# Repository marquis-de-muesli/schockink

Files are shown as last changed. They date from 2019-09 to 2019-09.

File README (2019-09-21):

NOTE: Schematics+Board are still IN-PROGRESS, i will announce once i am confident enough in them to put them into production myself.

How small can you go while keeping the full power and same (+more) features of a mk-312 box? :)
The answer is about 90x70x35mm, or about 1/8th of the original box.

Much thanks goes to metafetish and the buttshock project where i got started with the schematics.

To save cost and space, the entire control panel with LCD and mechanical buttons had to go.
The idea is to make a bluetooth app to take control instead.

Another major difference is that instead of a simple bluetooth bridge (HC05) i plopped in a whole new powerfull MCU (ESP32) on top of the original hardware.
The reason is twofold.
- The one thing we cant really replace with the ErosLink Protocol is the MA Knob, which is now replaced by a DigPot controlled by our new MCU.
- Eventually the idea is to tinker around with a new firmware from scratch, not just reuse the ET312 one.
  This Design allows to take full control of the Output Stage in the future.

Power will be supplied by 3x 18650 Lithium Cells. 
As of right now i haven't been able to cram in a charging circuit. So for now they are removable and charged in a tabletop charger.
The unintended side effect is that you could keep a spare set of batteries charged.

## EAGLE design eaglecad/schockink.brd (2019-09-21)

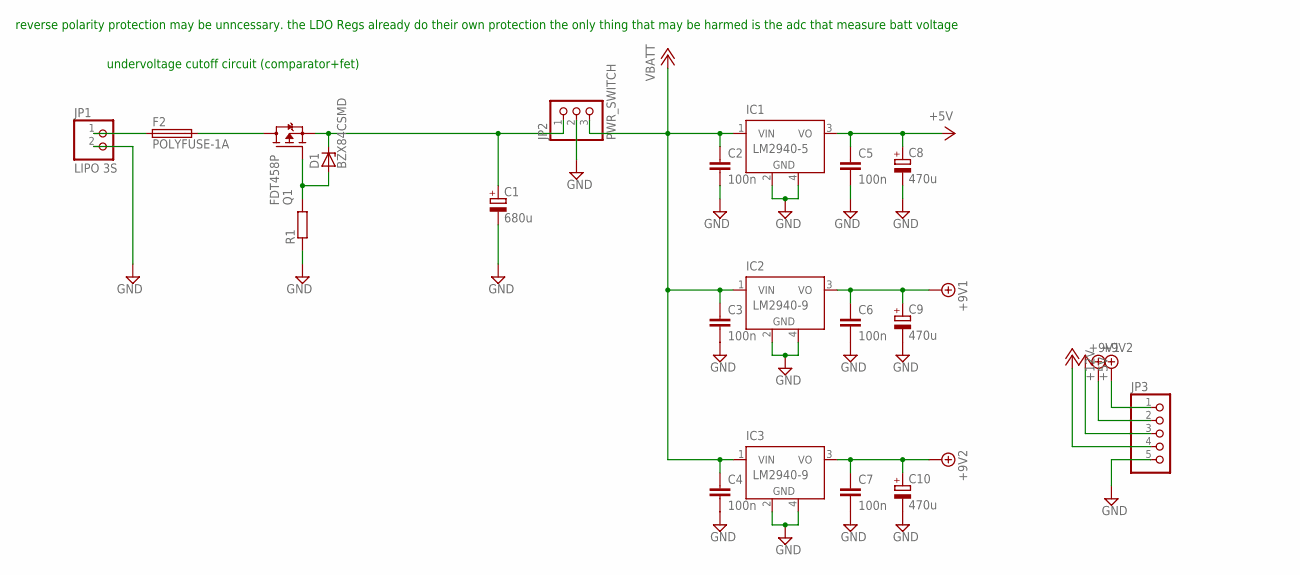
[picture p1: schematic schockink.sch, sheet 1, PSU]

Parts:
C1: 680u; UD-8X10_NICHICON
C2, C3, C4, C5, C6, C7: 100n; C2012
C8, C9, C10: 470u; UD-6,3X7,7_NICHICON
D1: BZX84CSMD; TO236
F2: POLYFUSE-1A; R1210
IC1: LM2940-5; SOT223
IC2, IC3: LM2940-9; SOT223
JP1: LIPO 3S; 1X02
JP2: PWR_SWITCH; 1X03
JP3: PINHD-1X5; 1X05
Q1: FDT458P; SOT223; MOUSER# 512-FDT458P
R1: R-EU_M2012; M2012

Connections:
+5V: C5.1, C8.+, IC1.3 (VO), JP3.3; also elsewhere on the board
+9V1: C6.1, C9.+, IC2.3 (VO), JP3.2; also elsewhere on the board
+9V2: C7.1, C10.+, IC3.3 (VO), JP3.1; also elsewhere on the board
+VBATT: C2.1, C3.1, C4.1, IC1.1 (VIN), IC2.1 (VIN), IC3.1 (VIN), JP2.3, JP3.4; also elsewhere on the board
GND: C1.-, C2.2, C3.2, C4.2, C5.2, C6.2, C7.2, C8.-, C9.-, C10.-, IC1.2 (GND), IC1.4 (GND), IC2.2 (GND), IC2.4 (GND), IC3.2 (GND), IC3.4 (GND), JP1.2, JP2.2, JP3.5, R1.1; also elsewhere on the board
unnamed: F2.1, JP1.1
unnamed: F2.2, Q1.2 (D), Q1.4 (D)
unnamed: D1.A, Q1.1 (G), R1.2
unnamed: C1.+, D1.C, JP2.1, Q1.3 (S)

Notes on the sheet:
reverse polarity protection may be unncessary. the LDO Regs already do their own protection the only thing that may be harmed is the adc that measure batt voltage
undervoltage cutoff circuit (comparator+fet)

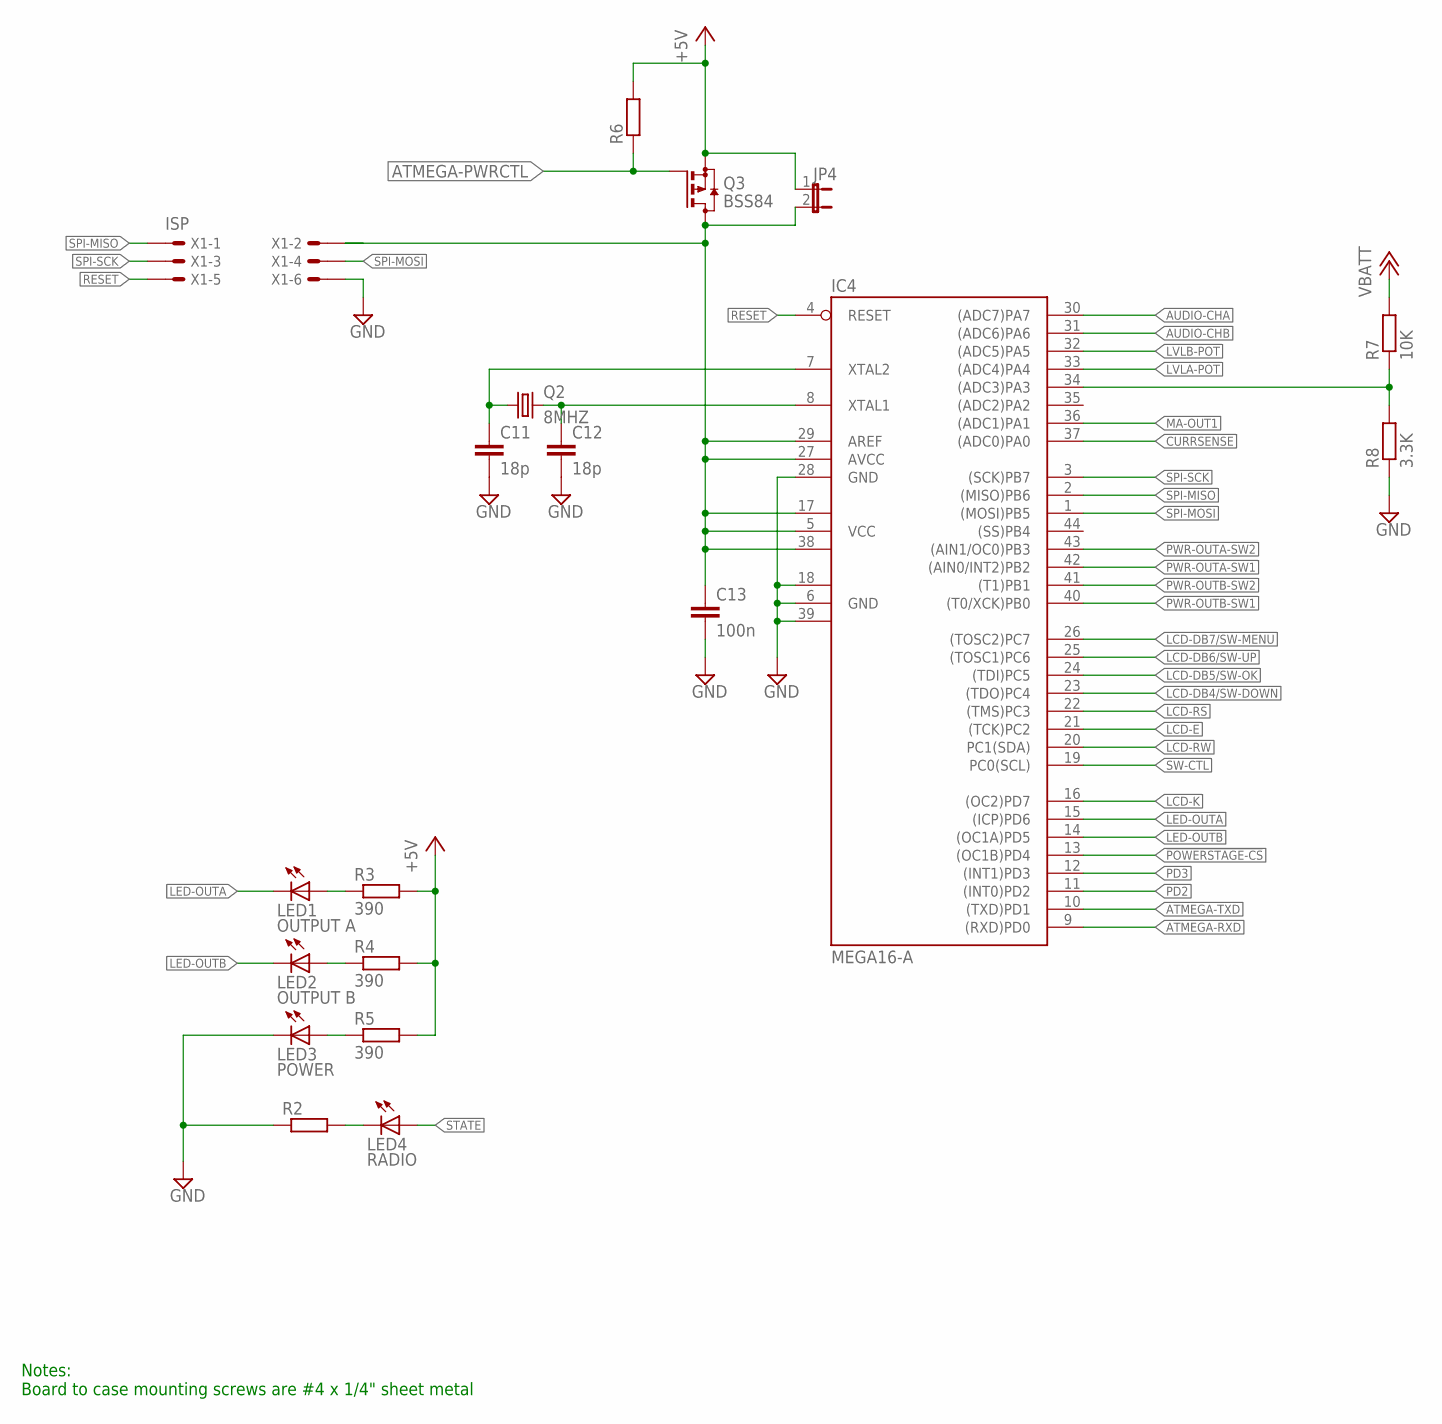
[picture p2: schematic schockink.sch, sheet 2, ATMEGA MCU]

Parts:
C11, C12: 18p; C2012
C13: 100n; C2012
IC4: MEGA16-A; TQFP44
JP4: JP1E; JP1
LED1: OUTPUT A; CHIPLED_0805
LED2: OUTPUT B; CHIPLED_0805
LED3: POWER; CHIPLED_0805
LED4: RADIO; CHIPLED_0805
Q2: 8MHZ; CTS406
Q3: BSS84; SOT23
R2, R6: R-EU_M2012; M2012
R3, R4, R5: 390; M2012
R7: 10K; M2012
R8: 3.3K; M2012
X1: ISP; 057-006-1

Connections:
!POWERSTAGE-CS: IC4.13 ((OC1B)PD4); also elsewhere on the board
+5V: JP4.1, Q3.2 (S), R3.2, R4.2, R5.2, R6.2; also elsewhere on the board
+VBATT: R7.2; also elsewhere on the board
ATMEGA-PWRCTL: Q3.1 (G), R6.1; also elsewhere on the board
ATMEGA-RXD: IC4.9 ((RXD)PD0); also elsewhere on the board
ATMEGA-TXD: IC4.10 ((TXD)PD1); also elsewhere on the board
AUDIO-CHA: IC4.30 ((ADC7)PA7); also elsewhere on the board
AUDIO-CHB: IC4.31 ((ADC6)PA6); also elsewhere on the board
CURRSENSE: IC4.37 ((ADC0)PA0); also elsewhere on the board
GND: C11.2, C12.2, C13.2, IC4.6 (GND), IC4.18 (GND1), IC4.28 (GND), IC4.39 (GND2), LED3.C, R2.1, R8.1, X1.6; also elsewhere on the board
LCD-DB4/SW-DOWN: IC4.23 ((TDO)PC4); also elsewhere on the board
LCD-DB5/SW-OK: IC4.24 ((TDI)PC5); also elsewhere on the board
LCD-DB6/SW-UP: IC4.25 ((TOSC1)PC6); also elsewhere on the board
LCD-DB7/SW-MENU: IC4.26 ((TOSC2)PC7); also elsewhere on the board
LCD-E: IC4.21 ((TCK)PC2); also elsewhere on the board
LCD-K: IC4.16 ((OC2)PD7)
LCD-RS: IC4.22 ((TMS)PC3); also elsewhere on the board
LCD-RW: IC4.20 (PC1(SDA))
LED-OUTA: IC4.15 ((ICP)PD6), LED1.C
LED-OUTB: IC4.14 ((OC1A)PD5), LED2.C
LVLA-POT: IC4.33 ((ADC4)PA4)
LVLB-POT: IC4.32 ((ADC5)PA5)
MA-OUT1: IC4.36 ((ADC1)PA1); also elsewhere on the board
unnamed: IC4.34 ((ADC3)PA3), R7.1, R8.2
unnamed: C13.1, IC4.5 (VCC), IC4.17 (VCC1), IC4.27 (AVCC), IC4.29 (AREF), IC4.38 (VCC2), JP4.2, Q3.3 (D), X1.2
unnamed: LED4.C, R2.2
unnamed: C12.1, IC4.8 (XTAL1), Q2.3 (2)
unnamed: LED2.A, R4.1
unnamed: LED1.A, R3.1
unnamed: C11.1, IC4.7 (XTAL2), Q2.1
unnamed: LED3.A, R5.1
PD2: IC4.11 ((INT0)PD2); also elsewhere on the board
PD3: IC4.12 ((INT1)PD3); also elsewhere on the board
PWR-OUTA-SW1: IC4.42 ((AIN0/INT2)PB2); also elsewhere on the board
PWR-OUTA-SW2: IC4.43 ((AIN1/OC0)PB3); also elsewhere on the board
PWR-OUTB-SW1: IC4.40 ((T0/XCK)PB0); also elsewhere on the board
PWR-OUTB-SW2: IC4.41 ((T1)PB1); also elsewhere on the board
RESET: IC4.4 (RESET), X1.5
SPI-MISO: IC4.2 ((MISO)PB6), X1.1
SPI-MOSI: IC4.1 ((MOSI)PB5), X1.4; also elsewhere on the board
SPI-SCK: IC4.3 ((SCK)PB7), X1.3; also elsewhere on the board
STATE: LED4.A; also elsewhere on the board
SW-CTL: IC4.19 (PC0(SCL)); also elsewhere on the board

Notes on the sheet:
Notes: Board to case mounting screws are #4 x 1/4" sheet metal

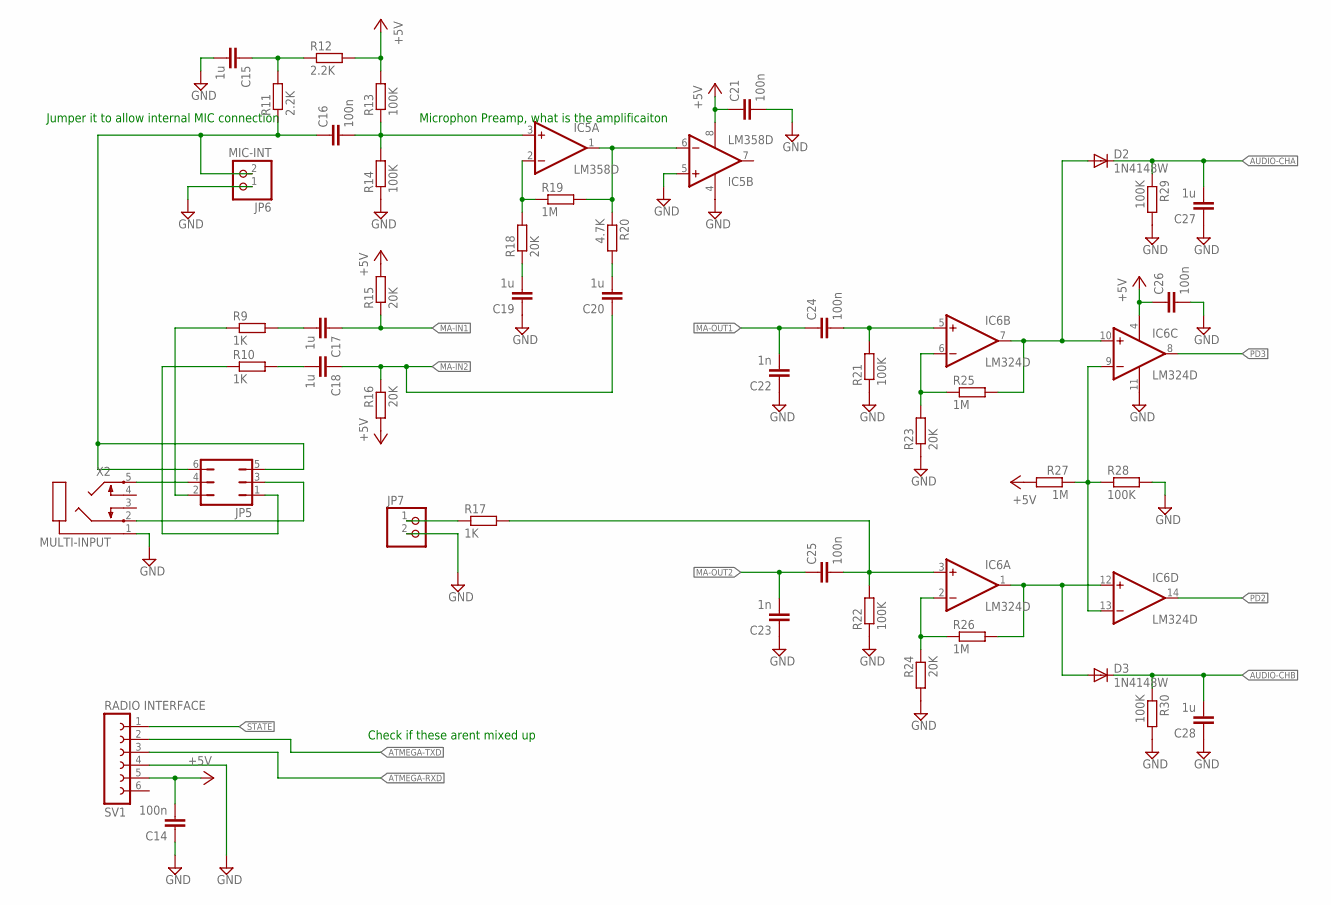
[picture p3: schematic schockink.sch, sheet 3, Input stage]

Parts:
C14, C16, C21, C24, C25, C26: 100n; C2012
C15, C17, C18, C19, C20, C27, C28: 1u; C2012
C22, C23: 1n; C2012
D2, D3: 1N4148W; SOD-123_MINI-SMA
IC5: LM358D; SO08
IC6: LM324D; SO14
JP5: JP3Q
JP6: MIC-INT; 1X02
JP7: PINHD-1X2; 1X02
R9, R10, R17: 1K; M2012
R11, R12: 2.2K; M2012
R13, R14, R21, R22, R28, R29, R30: 100K; M2012
R15, R16, R18, R23, R24: 20K; M2012
R19, R25, R26, R27: 1M; M2012
R20: 4.7K; M2012
SV1: RADIO INTERFACE; FE06
X2: MULTI-INPUT; STX3100

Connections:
+5V: C14.2, C21.1, C26.1, IC5.8 (V+), IC6.4 (V+), R12.2, R13.2, R15.2, R16.2, R27.2, SV1.5; also elsewhere on the board
ATMEGA-RXD: SV1.3; also elsewhere on the board
ATMEGA-TXD: SV1.2; also elsewhere on the board
AUDIO-CHA: C27.2, D2.C, R29.1; also elsewhere on the board
AUDIO-CHB: C28.2, D3.C, R30.1; also elsewhere on the board
GND: C14.1, C15.2, C19.1, C21.2, C22.1, C23.1, C26.2, C27.1, C28.1, IC5.4 (V-), IC5.5 (+IN), IC6.11 (V-), JP6.1, JP7.2, R14.1, R21.1, R22.1, R23.1, R24.2, R28.2, R29.2, R30.2, SV1.4, X2.1; also elsewhere on the board
MA-IN1: C17.1, R15.1; also elsewhere on the board
MA-IN2: C18.1, C20.1, R16.1; also elsewhere on the board
MA-OUT1: C22.2, C24.1; also elsewhere on the board
MA-OUT2: C23.2, C25.1; also elsewhere on the board
unnamed: JP7.1, R17.1
unnamed: JP5.4, X2.5
unnamed: JP5.3, X2.2
unnamed: C25.2, IC6.3 (+IN), R17.2, R22.2
unnamed: JP5.2, R9.1
unnamed: JP5.1, R10.1
unnamed: C19.2, R18.1
unnamed: IC6.2 (-IN), R24.1, R26.1
unnamed: D3.A, IC6.1 (OUT), IC6.12 (+IN), R26.2
unnamed: C17.2, R9.2
unnamed: IC6.6 (-IN), R23.2, R25.1
unnamed: IC6.9 (-IN), IC6.13 (-IN), R27.1, R28.1
unnamed: C24.2, IC6.5 (+IN), R21.2
unnamed: C18.2, R10.2
unnamed: D2.A, IC6.7 (OUT), IC6.10 (+IN), R25.2
unnamed: C16.1, JP5.5, JP5.6, JP6.2, R11.1
unnamed: C15.1, R11.2, R12.1
unnamed: C16.2, IC5.3 (+IN), R13.1, R14.2
unnamed: IC5.2 (-IN), R18.2, R19.1
unnamed: IC5.1 (OUT), IC5.6 (-IN), R19.2, R20.1
unnamed: C20.2, R20.2
PD2: IC6.14 (OUT); also elsewhere on the board
PD3: IC6.8 (OUT); also elsewhere on the board
STATE: SV1.1; also elsewhere on the board

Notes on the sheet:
Jumper it to allow internal MIC connection
Check if these arent mixed up
Microphon Preamp, what is the amplificaiton

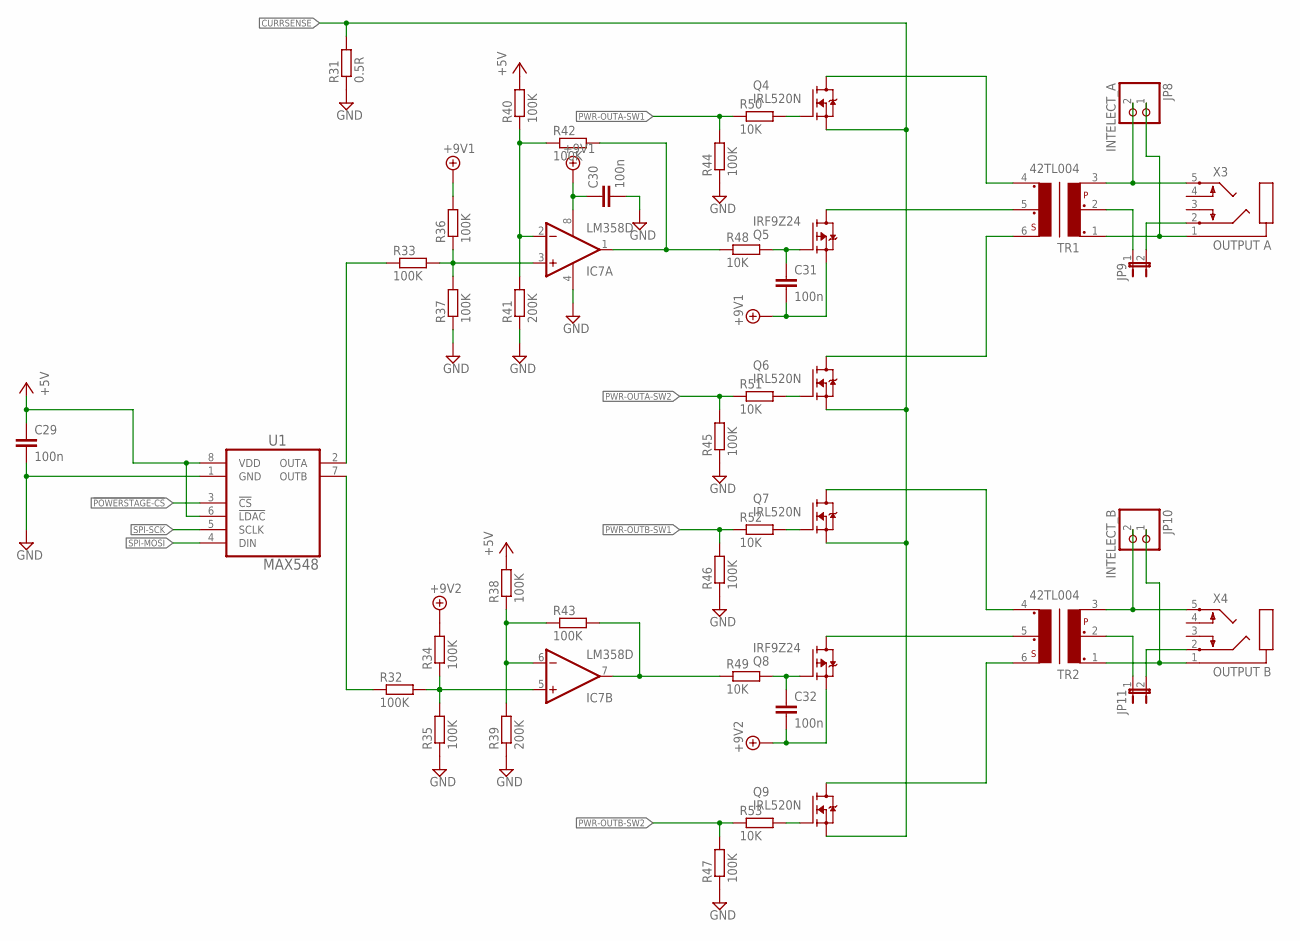
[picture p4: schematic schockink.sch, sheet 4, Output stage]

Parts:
C29, C30, C31, C32: 100n; C2012
IC7: LM358D; SO08
JP8: INTELECT_A; 1X02
JP9, JP11: JP1E; JP1
JP10: INTELECT_B; 1X02
Q4, Q6, Q7, Q9: IRL520N; TO263
Q5, Q8: IRF9Z24; TO263
R31: 0.5R; M2012
R32, R33, R34, R35, R36, R37, R38, R40, R42, R43, R44, R45, R46, R47: 100K; M2012
R39, R41: 200K; M2012
R48, R49, R50, R51, R52, R53: 10K; M2012
TR1, TR2: 42TL004; 42TL; MOUSER# 42TL004-RC
U1: MAX548; UMAX8
X3: OUTPUT A; STX3100
X4: OUTPUT B; STX3100

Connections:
!POWERSTAGE-CS: U1.3 (!CS); also elsewhere on the board
+5V: C29.1, R38.2, R40.2, U1.6 (!LDAC), U1.8 (VDD); also elsewhere on the board
+9V1: C30.1, C31.2, IC7.8 (V+), Q5.2 (S), R36.2; also elsewhere on the board
+9V2: C32.2, Q8.2 (S), R34.2; also elsewhere on the board
CURRSENSE: Q4.2 (S), Q6.2 (S), Q7.2 (S), Q9.2 (S), R31.2; also elsewhere on the board
GND: C29.2, C30.2, IC7.4 (V-), R31.1, R35.1, R37.1, R39.1, R41.1, R44.1, R45.1, R46.1, R47.1, U1.1 (GND); also elsewhere on the board
unnamed: Q5.3 (D), TR1.5
unnamed: Q8.3 (D), TR2.5
unnamed: JP11.1, TR2.2
unnamed: JP8.1, TR1.1, X3.1
unnamed: Q4.1 (G), R50.2
unnamed: Q6.1 (G), R51.2
unnamed: JP11.2, X4.2
unnamed: C31.1, Q5.1 (G), R48.2
unnamed: IC7.3 (+IN), R33.2, R36.1, R37.2
unnamed: Q7.1 (G), R52.2
unnamed: Q9.1 (G), R53.2
unnamed: JP10.1, TR2.1, X4.1
unnamed: C32.1, Q8.1 (G), R49.2
unnamed: IC7.5 (+IN), R32.2, R34.1, R35.2
unnamed: Q4.3 (D), TR1.4
unnamed: JP8.2, TR1.3, X3.5
unnamed: Q7.3 (D), TR2.4
unnamed: JP10.2, TR2.3, X4.5
unnamed: Q9.3 (D), TR2.6
unnamed: Q6.3 (D), TR1.6
unnamed: IC7.2 (-IN), R40.1, R41.2, R42.1
unnamed: IC7.6 (-IN), R38.1, R39.2, R43.1
unnamed: R33.1, U1.2 (OUTA)
unnamed: JP9.2, X3.2
unnamed: JP9.1, TR1.2
unnamed: R32.1, U1.7 (OUTB)
PFET_A: IC7.1 (OUT), R42.2, R48.1
PFET_B: IC7.7 (OUT), R43.2, R49.1
PWR-OUTA-SW1: R44.2, R50.1; also elsewhere on the board
PWR-OUTA-SW2: R45.2, R51.1; also elsewhere on the board
PWR-OUTB-SW1: R46.2, R52.1; also elsewhere on the board
PWR-OUTB-SW2: R47.2, R53.1; also elsewhere on the board
SPI-MOSI: U1.4 (DIN); also elsewhere on the board
SPI-SCK: U1.5 (SCLK); also elsewhere on the board

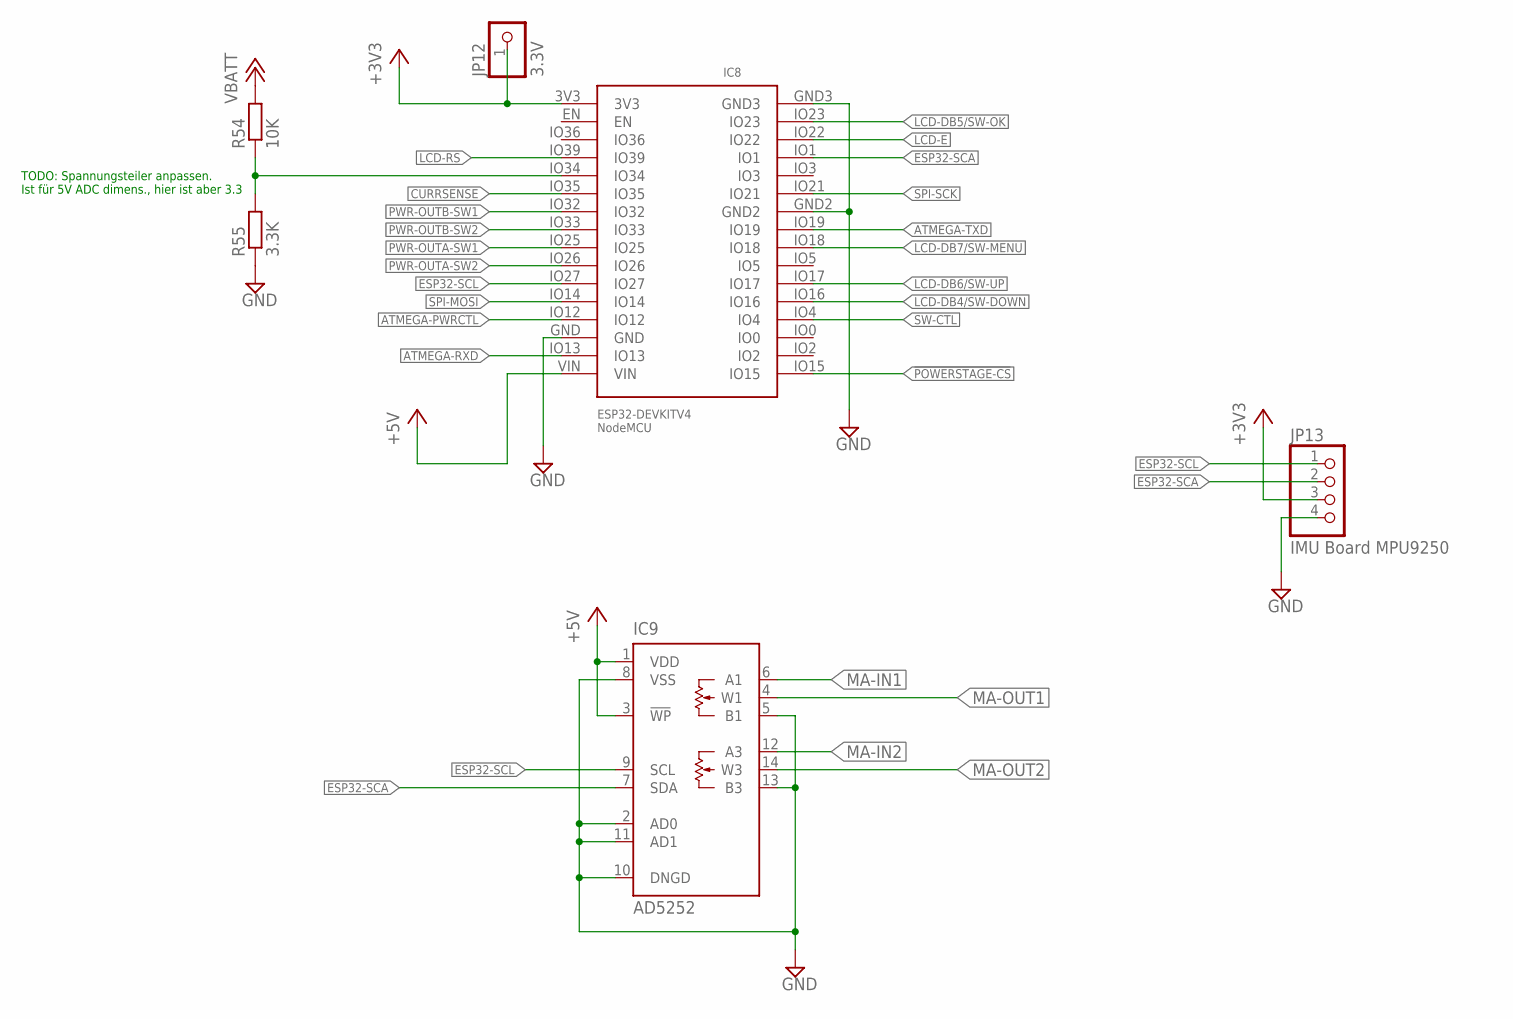
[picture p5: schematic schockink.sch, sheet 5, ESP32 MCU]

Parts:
IC8: ESP32DEVKIT; ESP32-DEVKIT
IC9: AD5252; TSSOP14
JP12: 3.3V; 1X01
JP13: IMU Board MPU9250; 1X04
R54: 10K; M2012
R55: 3.3K; M2012

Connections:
!POWERSTAGE-CS: IC8.IO15; also elsewhere on the board
+3V3: IC8.3V3, JP12.1, JP13.3
+5V: IC8.VIN, IC9.1 (VDD), IC9.3 (!WP); also elsewhere on the board
+VBATT: R54.2; also elsewhere on the board
ATMEGA-PWRCTL: IC8.IO12; also elsewhere on the board
ATMEGA-RXD: IC8.IO13; also elsewhere on the board
ATMEGA-TXD: IC8.IO19; also elsewhere on the board
CURRSENSE: IC8.IO35; also elsewhere on the board
ESP32-SCA: IC8.IO1, IC9.7 (SDA), JP13.2
ESP32-SCL: IC8.IO27, IC9.9 (SCL), JP13.1
GND: IC8.GND, IC8.GND2, IC8.GND3, IC9.2 (AD0), IC9.5 (B1), IC9.8 (VSS), IC9.10 (DNGD), IC9.11 (AD1), IC9.13 (B3), JP13.4, R55.1; also elsewhere on the board
LCD-DB4/SW-DOWN: IC8.IO16; also elsewhere on the board
LCD-DB5/SW-OK: IC8.IO23; also elsewhere on the board
LCD-DB6/SW-UP: IC8.IO17; also elsewhere on the board
LCD-DB7/SW-MENU: IC8.IO18; also elsewhere on the board
LCD-E: IC8.IO22; also elsewhere on the board
LCD-RS: IC8.IO39; also elsewhere on the board
MA-IN1: IC9.6 (A1); also elsewhere on the board
MA-IN2: IC9.12 (A3); also elsewhere on the board
MA-OUT1: IC9.4 (W1); also elsewhere on the board
MA-OUT2: IC9.14 (W3); also elsewhere on the board
unnamed: IC8.IO34, R54.1, R55.2
PWR-OUTA-SW1: IC8.IO25; also elsewhere on the board
PWR-OUTA-SW2: IC8.IO26; also elsewhere on the board
PWR-OUTB-SW1: IC8.IO32; also elsewhere on the board
PWR-OUTB-SW2: IC8.IO33; also elsewhere on the board
SPI-MOSI: IC8.IO14; also elsewhere on the board
SPI-SCK: IC8.IO21; also elsewhere on the board
SW-CTL: IC8.IO4; also elsewhere on the board

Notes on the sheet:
TODO: Spannungsteiler anpassen. Ist für 5V ADC dimens., hier ist aber 3.3

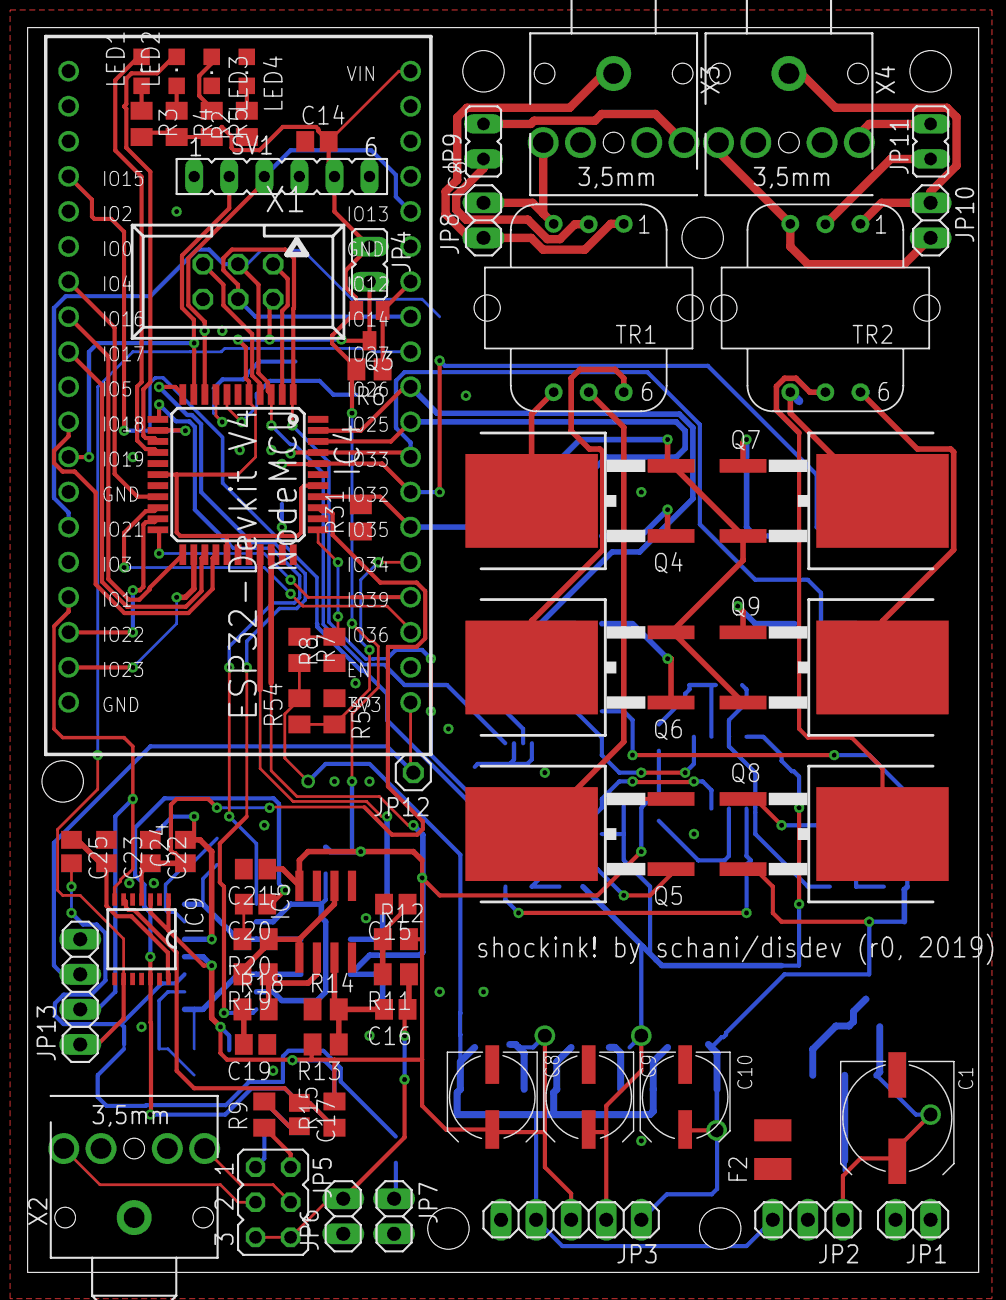
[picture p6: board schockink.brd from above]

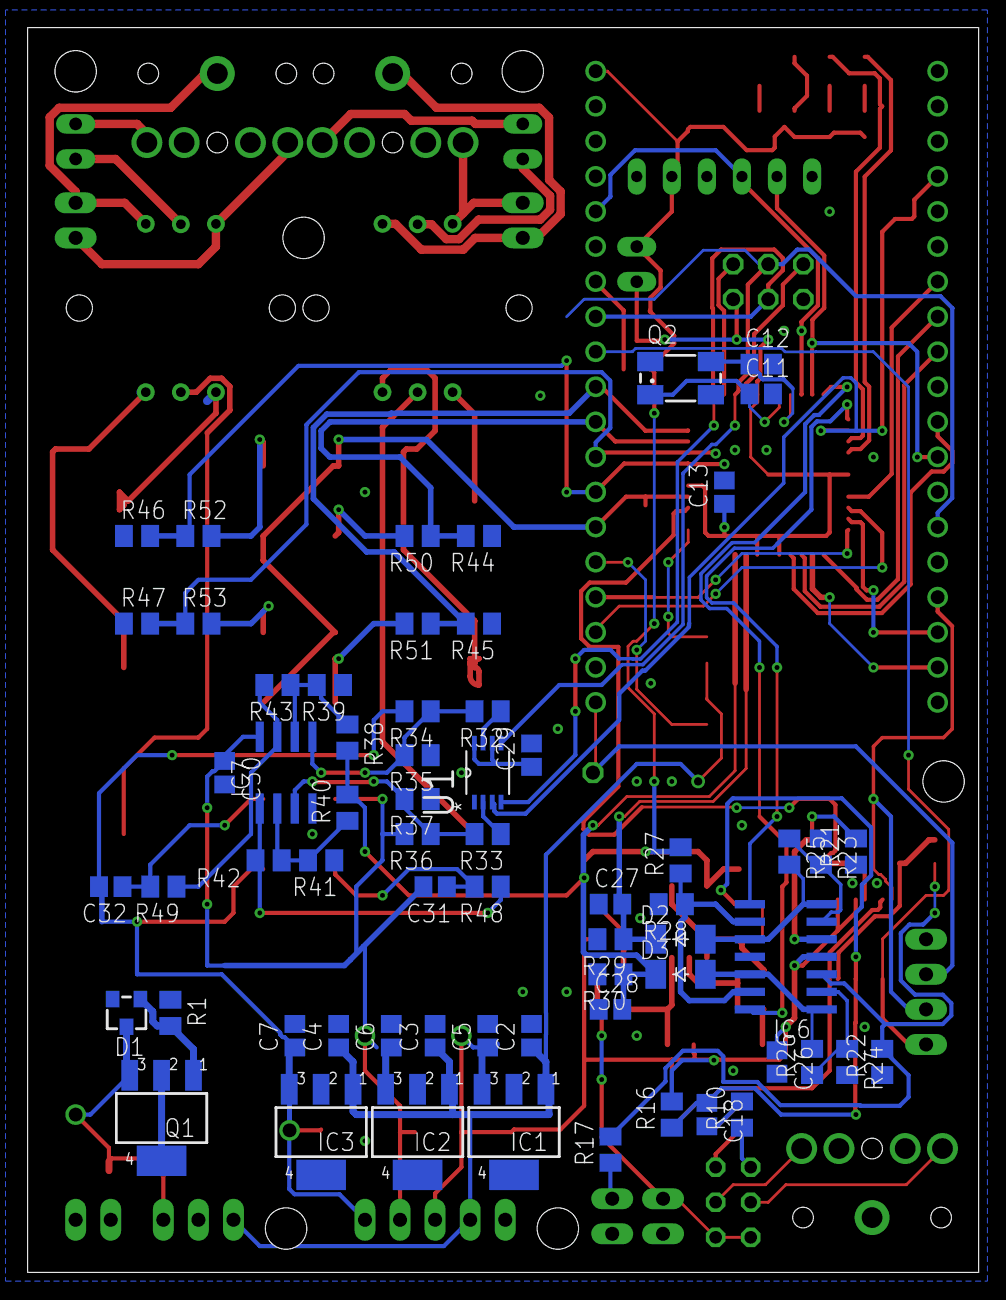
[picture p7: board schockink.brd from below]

Board: 2 copper layers, 68.9 x 90.2 mm, 134 parts (64 on the bottom side), 101 nets.
